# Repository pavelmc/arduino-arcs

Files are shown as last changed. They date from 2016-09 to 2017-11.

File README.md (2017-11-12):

# Arduino-Arcs #

_**Amateur Radio Control & Clocks (RF) Solution**_

This is an amateur approach to a radio control solution with clock (RF sources) generation (VFO and BFO) for homebrewed and old (not frequency synthesized) transceivers; of course based on the Arduino platform.

You can [take a peek here](http://www.qrz.com/db/wj6c) to see what's it looks like in the bench.

## Motivations ##

This project arose as a solution for the Cuban hams who have built a simple QRP transceivers but lacks the principal part: a digital controller to avoid the "DRIFT" and get some of the standard radio features a ham's needs today in a radio.

[Juan Carlos (WJ6C)](http://www.qrz.com/db/wj6c), Axel (CO6ATL), [Heriberto (CM2KMK)](http://www.qrz.com/db/wj6c) and many others hams were trying with some Arduino sketches found on the network until [I (CO7WT)](http://www.qrz.com/db/co7wt) decided to give a hand using my skills and expertise on MCU programming with [Jal for the PICs](http://www.justanotherlanguage.com) & [Arduino](http://www.arduino.cc).

This code is the result of a group of Cubans that joint together to fulfill the expectations for a simple, affordable and yet modern radio logic controller for homebrewed radios that any ham in the world can use.

This work is and always will be in constant development, this must be always considered a Beta version.

## Hardware ##

We are using the ubiquitous Arduino boards for the main brain, a list of the needed hardware follows.

- Arduino as the brain; developed for the Arduino Uno R3 as base, but it's adaptable to other boards, we are using mainly the Mini & Mini Pro now (Yes it's less than 16 kb at the end)
- LCD 16 columns and 2 lines as display (LiquidCrystal default Arduino lib)
- Si5351 as VFO and BFO, any of the breakout board out there will work, we choose to use a embedded code for the Si5351 control. Our code is a modified version of one of the examples in the [QRP Labs site](http://qrp-labs.com) (with my mods to allow two outputs instead of only one) and trick learned from [DK7IH](https://radiotransmitter.wordpress.com/category/si5351a/) to eliminate the unpleasant clicks when tunning. You can use it as a full library named [Si5351mcu here](http://github.com/pavelmc/si5351mcu).
- For the human interface part we use a bunch of [analog push buttons with dual functions](https://github.com/pavelmc/BMUx/) and a [rotary encoder](https://github.com/mathertel/RotaryEncoder) + [push button](https://github.com/thomasfredericks/Bounce2/).
- Since September of 2016 the sketch has CAT support, if you are using an Arduino R3 or others with a USB port you are done; if not you need any of the [cheap ebay USB to RS-232/TTL converters](http://www.google.com/q=cp-2021+USB+serial+ttl+converter) just watch out for the correct drivers if you use any Windows OS.

You can see the schematic diagram (designed for an Arduino Uno R3 in mind) in the file sketch_schema.png (I can provide Fritzing files on request, but only the schematic part is ok.)

## Features implemented by now ##

- **Usual features** of normal commercial transceivers.
    - Two VFO (A/B)
    - RIT with +/- 9.99 Khz
    - Variable VFO speed in steps of 10hz, 100hz (Default), 1khz, 10khz, 100khz, 1Mhz (just push of the encoder)
    - Split for contest/pileups
    - VFOs A & B are preserved in the EEPROM across power cycle. _(See Note 1 below)_
- **S-Meter in the LCD** _(Vref is 5.0V)_ _(See Note 2 below)_
- **Relative TX power in the LCD** _(using the same S-Meter tech, no power calcs, yet)_
- Initially mono-band in 40m, but **adaptable to any band**
- **Full user customization** of the IF and BFO modes (side bands) via configuration menus. (The VFO is assumed always above the RF and side bands are adjusted, se notes on Si5351 noise)
- **Hot tunning of the parameters** when in configuration mode for ease the adjust.
- **Basic CAT control** (like a Yaesu FT-857D) using my GPL 3.0 [ft857d library](https://github.com/pavelmc/ft857d) _(See Note 3 below)_
- The sketch is coded with **feature segmentation in mind**, you can rule out the CAT support if you don't need it, disable the ugly S-meter or rule out all other HID and just compile with CAT to get a slim CAT radio solution that fits in a tiny ATMega8 core _(I'm no kidding, it do fit in that chip!)_
- **Memories** Using the internal EEPROM and limited to 100 (0-99), because the channel number is displayed in two LCD chars. Also you will get what your Chip has to offer: bigger chips my exceed the 100 mem channels count and get toped, but other not and you will have less than 100 mem channels.
- ** Scan in memories ** if you enable the memories in the compilation you have also the possibility of enable the scanning features to loop trough the active memories and stay in each one by a defined amount of time.

_**Note 1:** The firmware save the VFO info in a 10 minutes interval. Also a touch on the "VFO A/B" button will force an update_

_I was once concerned with the EERPOM wear out, but not anymore: The auto-save every 10 minutes **with a heavy use** of the transceiver can lead to about 3 years of life for the internal EEPROM _under datasheet conditions_. But you can expect at least x2 of that amount as the real world data shows (that's at least 6 years with heavy use or more than 10 years with little use)_

_Since October 2016 we are now using the new EEPROM.h library (since Arduino IDE 1.6.9 and later); that lib do a trick to preserve the internal EEPROM life against the wear out, so the real life of the EEPROM must be more than 6 years minimum, that for a **heavy daily use**._

_**Note 2:** You have two options for the SMeter graphics, the default now is a 26 steps solid bars like "|||||||||||||||" and the alternative is the old "1-3-5-7-9----" with a resolution of only 13 steps. You can change it via a #define in the code, read it._

_**Note 3:** If you use a regular Arduino board and upload the code via serial port you do have a bootloader in place. In this case when you setup your CAT program (in your PC) you will have to set the "retries" parameter to 3 or more and the "timeout" parameter to 500 msec or more to get the CAT working. (you will have to play with it a bit to get it working)_

_This is because the CAT setup process in your PC/software will reset the Arduino board (and hence the "radio")_

_Then the bootloader will introduce a short delay before our firmware kicks in and the PC may complain about "radio not answering to commands". The fix is in the previous paragraph. If you have no bootloader and upload the code via ICP you must not see this problems._

## Features in the TODO list ##

This are the wish list so far, with no particular order.

- Multi-band support with a function to jump quickly from band to band.
- Band selector for BPF switching via a external I2C port expander like the boards with the PCF8574, or alternatively a PIC programed to the task.
- Real Power and SWR measurements.
- Support for various LCDs, for example the Nokia 5110, some of the TFTs and some OLEDs.

## Ino, then Arturo, now Amake ##

Old users of this sketch may notice that it's now full Arduino IDE compatible _(since January/2017 with the release of the Arduino IDE version 1.8.0)_ and you don't need to make any more changes to the name of the file.

I use Ubuntu Linux for daily work here, and I don't like the Arduino IDE as a IDE. I use the [Geany IDE](http://www.geany.org) to code in Jal, Python, Arduino etc. In the past two projects helped me to link my Geany IDE to the Arduino tool-chain: [ino](https://github.com/amperka/ino) and it's folk [Arturo](https://github.com/scottdarch/Arturo/) when Ino reached the end of development. Thanks to the developers of this two projects for the great tools.

Since the release of the Arduino IDE version 1.8.0 it's possible to use a new tool "arduino-builder" that make possible to compile and upload a sketch entirely from the command line, but that tool is a nightmare to configure for the job in the command line.

And that was the born of [Amake](https://github.com/pavelmc/amake/), this a bash script that introduce a layer to get the compilation and uploading of arduino sketches from the command line like a breeze, and it's full Arduino IDE compatible. It's my contribution to make the life simpler ;-)

## Si5351 known issues ##

The Si5351 chip is not the panacea of the frequency generator (but it's a close one), as almost all good things in life it has a dark side, know more about in [this](https://github.com/pavelmc/arduino-arcs/Si5351_issues.md) document.

73 Pavel CO7WT.

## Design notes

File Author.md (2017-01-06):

# Author #

I'm Pavel Milanes, the main developer of this sketch and can be reached at pavelmc@gmail.com I'm an active amateur radio operator under the call sign CO7WT, and I live in Camagüey, Cuba, the Caribbean island, exactly at the FL11aj locator. I'm active from time to time around 7.125 Khz on 40m from 2200z to 0200z on weekdays.

## Acknowledge to direct & indirect contributors ##

This work is based on the previous work of these people (without their work this project may not exist):

 * [NT7S](https://github.com/etherkit/Si5351Arduino) for his work on the Silabs Si5351 and the Arduino library.
 * Ben Buxton & [mathertel](https://github.com/mathertel/RotaryEncoder) for the arduino rotary encoder library
 * [Thomas Ouellet](https://github.com/thomasfredericks/Bounce2/) for the Bounce2 library
 * [SQ9NJE](http://sq9nje.pl) for the example codes and it's sketchs.
 * [AK2B](http://ak2b.blogspot.com) for his multifeatured VFO in which this code is based.
 * [WJ6C](www.frcuba.com) for the idea and support, this OM is the motor of this project.
 * [QRP Labs](http://qrp-labs.com) explanation and examples of libraries for the Si5351 with MCU (size) focus.
 * Many other hams elsewhere with critics, opinions, public code on the Internet and ideas.

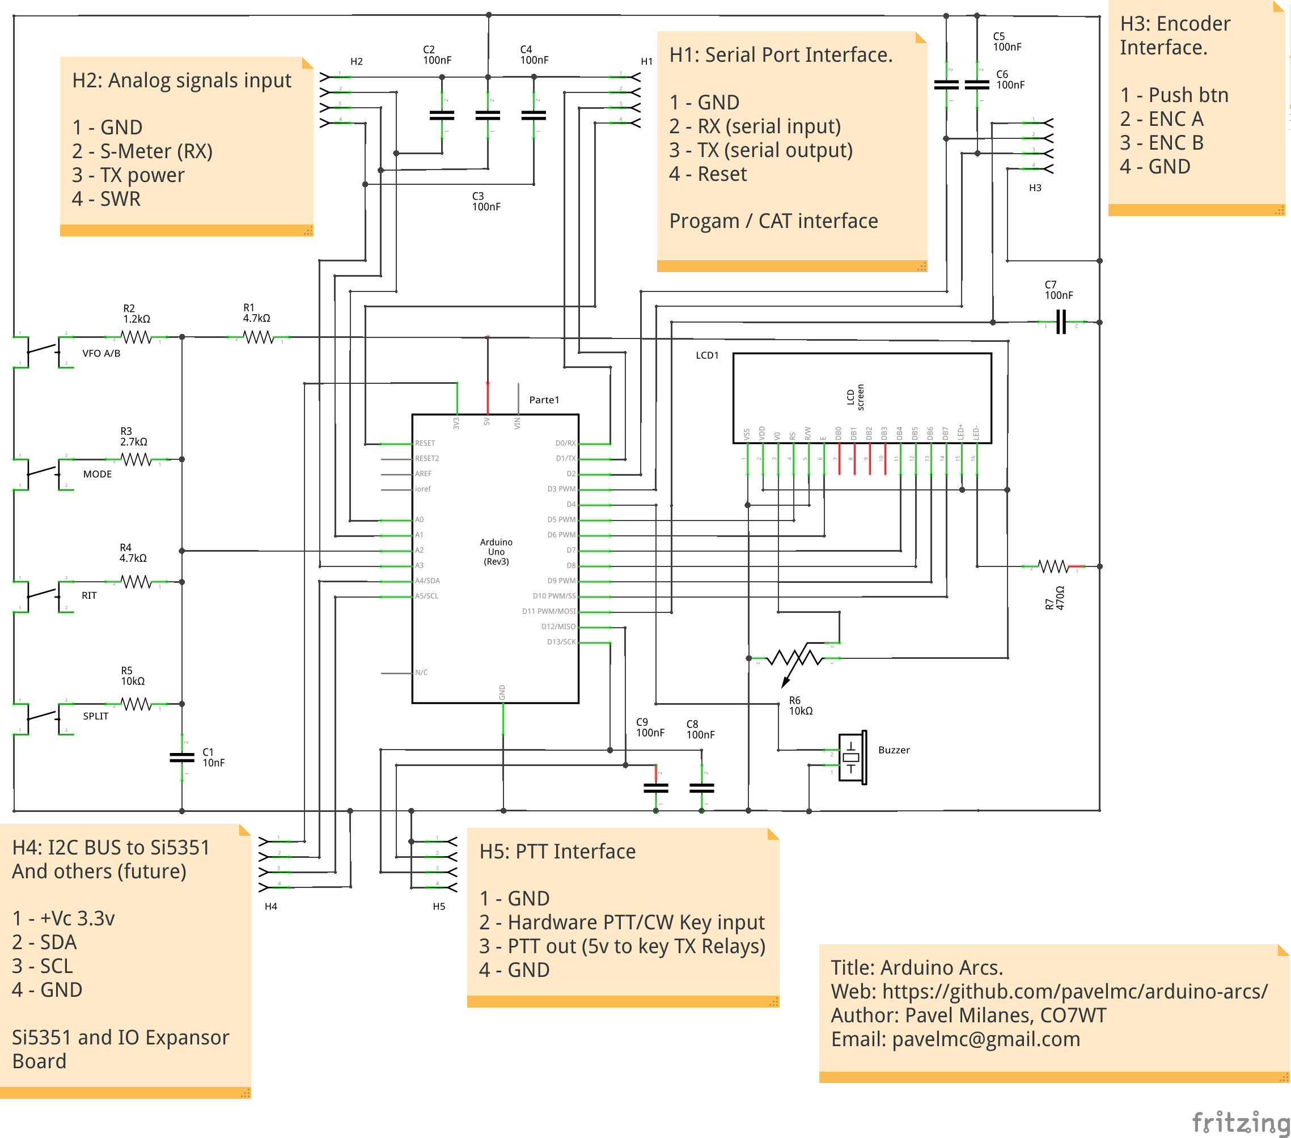
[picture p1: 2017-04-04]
sketch_schema.png

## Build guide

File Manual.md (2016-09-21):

Arduino ARCS Manual
=========================

# OUTDATED, will be upgraded soon #

This is a short manual to know how to operate the sketch and the button's functions. The sketch has two modes, the user's mode and the setup mode, let's review them

User mode
=========

General description
-------------------

The user mode is the natural way the hardware boots if you don't touch anything, yo will see the Arduino ARCS banner and a note of the firmware version, the memory firmware version and the author, then you will get the main screen.

The main screen is composed of two lines the top line and the bottom line, both lines has the same information for each of the two VFOs the sketch has, upper is VFO A and lower is VFO B. You know which VFO is selected by the ">" sign in front of it.

The frequency is printed grouped by units and separated by a dot to easy viewing, first the Mhz units, then the khz part and finally the Hz part.

The frequency is truncated at the 10th of hz part to be honest, the Si5351 has a resolution of 0.1 hz in our configuration and an accuracy of 0 ppm error against the reference crystal used (that's per the OEM datasheet), then all the accuracy is referenced to the accuracy of the reference crystal and it has (usually on free air) about 10 ppm of error; using a 27 Mhz xtal we can expect a extreme variation of about 270 hz with temperature, voltage and humidity fluctuations.

In the best case scenario if you have a relatively stable operating temperature and humidity you can get about less 10hz of variation normally under this conditions.

This is why we have not 1hz accuracy in place, we can implement it, sure, the chip will be happy moving in 1hz steps but that "accuracy" will be undermined by the real stability of the reference crystal unless you managed to get a temp oven for the crystal, and that is an overkill to out goal.

If you have a crystal in an oven and you want to use 1hz steps I will be happy to mod the sketch for you.

VFO button
----------

This Button toggles from the two available VFOs, as simple as that.

RIT button
----------

This button toggles the RIT function for the **active** VFO and will show the RIT detail in the other position, the RIT uses a +/- 9.9 Khz, so you can go further than that; this can be modified by software. When you have the RIT active and hit this button again, it will reset the VFO to the previous value as you expect.

The step on the RIT mode is fixed by software at 100hz, you can get it at the 10hz step if you change it on the source code in the sketch.

A note: when you have the RIT active on one VFO and you want to switch to the other VFO the active RIT will be reseted before the switch to the other VFO.

MODE button
-----------

The mode button change the mode of the **active** VFO in a closed loop from one of the predefined modes, so far: LSB > USB > CW and then back to LSB.

STEP button _(encoder push button)_
---------------------------------

The encoder push button has the control of the steps in the rotation of the encoder, pushing it will cycle steps in 10hz, 100hz, 1khz, 10khz, 100khz and 1 Mhz and then back to 10hz.

Upon the modification of the step, the LCD will show the value in the area used to show the S-meter bargraph for about three seconds.

Encoder
-------

The encoder is simply the vernier to selecting the frequency of the active VFO in the steps selected by the push button described before.

SETUP mode
==========

The setup mode is reached by powering on the circuit and holding the encoder button pressed until you see the acknowledge in the LCD for it being on the SETUP mode.

In the setup mode you will find a menu with the following options to select and change on the encoder rotation and push.

 * IF frequency
 * VFO A start frequency
 * VFO B start frequency
 * VFO frequency for the LSB mode
 * VFO frequency for the USB mode
 * VFO frequency for the CW mode
 * VFO A start mode
 * VFO B start mode
 * XFO frequency
 * Si5351 PPM error correction

All this options are cycled via the encoder rotation in one or another direction and selected via the encoder push button; we will describe the buttons use in the setup mode and be aware that they change a little in the setup mode, we will name it as the usual function and will name the special function between parenthesis.

Encoder push button _(Select & Confirm)_
-----------------------------------

This button is used to select the option in the main menu to be modified, and also to confirm it's change after it was modified and get it back to the main menu saving it on the EERPOM.

MODE button _(Cancel)_
--------------------

This button has effect only when you have selected and option in the main menu and it's purpose is to leave this option unchanged and get back to the main menu. If you changed the value of an option selected (by rotating the encoder) but you want to cancel it's modification this option is what you need.

RIT button _(Step)_
-----------------

This button has only effect when you have selected to modify a menu entry that leads to a numeric option (for example frequencies, PPM error, etc.) and it will change the step for the encoder rotation showing the value selected in the LCD until you rotate the encoder.

VFO button _(Reset)_
------------------

This button has a special meaning in the options refereed to LSB & USB BFO frequencies and the Si5351 PPM correction. Pressing this buttons will reset the values of that option to it's default values as this:

 * BFO LSB frequency = -15000
 * BFO USB frequency = +15000
 * BFO CW frequency = +10000
 * Si5351 PPM error correction = 0

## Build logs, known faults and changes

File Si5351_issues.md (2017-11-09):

# Si5351 Clock generator issues #

There are some founded worries about the use of the Si5351 Clock generator in transceiver business, and now with more and more builders using it, that problems are beginning to fade away.

This article will grow with experience notes about the problems and our experience about them. For the record, we have so far 5 different setups testing this sketch + hardware.

* BitX 20 _(converted to 40m, IF 8.2158 Mhz from a FT-747GX SSB filter, **CO7WT**)_
* Anritsu transceiver _(Unknown model, IF1 1.6 Mhz, IF2 455 Khz, **CO7LX**)_
* RFT SEG-15 _(WWII transceiver, IF1 28.2 Mhz, IF2 200 Khz, **CO7KD**)_
* Furuno FS1000 _(IF 9 Mhz, **CO7YB**)_
* Homebrew 500Khz singe conversion SSB radio _(Using a SSB filter from a USSR/CCCP "KARAT" transceiver, **CM7MTL**)_

Please note that almost all of this radios are actually kind of Frankenstein's cousins, as they preserve the main RF/IF chain from the mentioned radios, but can have another final stage (homebrewed or borrowed for a commercial unit) as well as chassis/front panels, etc.

## Crosstalk ##

Some users are pointing that the outputs of the chip is not clean enough for the use in heterodyne transceivers, [here you can see of what we are talking about](http://nt7s.com/2014/12/si5351a-investigations-part-8/), as you can see, some of the signal of one output can sneak into the other output, this is a proved bad thing.

Then the question now is: **how bad is it?**

The graphs in the last link shows the worst scenario, you can see that the worst case is only about -35 dB down the main frequency, that will result in about 25mW of the spurious frequency at the output of a main signal with 100W for the fundamental frequency.

With proper measures in design and other tricks (Bandstop/bandpass filters) you can get that crosstalk down below 50dB and the problem can be minimized at the point to be almost eliminated.

### Experience from our side ###

From a technician point of view with laboratory grade equipment, you are gonna find the crosstalk, it's there. From a normal homebrewer with COTS (Cost Off The Shelf) equipment it's not a big deal on reception and it has a no-noticeable impact on your transmission even with 150W in one of our local setups.

## Square wave output ##

Thanks to Mr. Fourier we know that square waves are a pure sine wave of the fundamental frequency plus all the harmonics of it until infinity... but a signal full of it's harmonics is a bad thing in a VFO or any other place where we need a pure sine signal, right?

That's why we designed the sketch to always use a final VFO frequency **above** the fundamental RF frequency and all the outputs of the chips will be followed with a matched low pass or a band pass filter to get rid of the most of the harmonics to minimize this problem.

Reception is affected in a different manner even when the VFO is over the RF; if you had to generate a BFO or a VFO signal below 2Mhz you will get more and more spurious spikes across the spectrum. Eventually at a BFO of 455/500 kHz you will need some filtering in place for a proper operation.

A trick from one of our builders CO7LX: he has a 1rst IF of 1.6 MHz then a second IF of 455 kHz. The reception with the BFO at 455 kHz coupled directly (just a dc blocking capacitor) was really poor. After inspection wit and SDR we noted a lot of spurious spikes and an unusual high noise floor.

As this signal is fixed and if needed just moved a couple of kHz we make a simple filter with two TOKO IF cans coupled back to back to form a crude and yet simple band pass filter and we managed to push down the noise floor and the numerous spurious signals to a very pleasant level.

### Experience from our side ###

The simple fix is to put a low pass filter for the used frequency range, or even better, a band pass filter you will be safe and this will do the job, believe us, this is a "must" not an "if".

## Jitter & phase noise ##

There are some sources talking about the jitter in the output frequencies, but this author can't find any technical info on the web about how bad is it.

For SSB communications we (humans) can tolerate a jitter of about 2-5 hz without noticing it, and free running LC oscillators can have more than that and we can deal with that, so I think this will not defeat the purpose of this Chip as a frequency generator in the cheap ham market.

The code for managing the Si5351 uses a integer division always, with that we get sure you get as low jitter and phase noise as possible.

## Birdies and Background Noise ##

In almost all setups out there in the internet you will find a few users talking about the birdies in the receiver and even about an artificial (high) background noise, well, after experimentation with this setup with a few receiver configurations here in Cuba I can tell you this:

1 - Not all birdies comes from the Si5351, some are Arduino and/or LCD related.

In one of my setups I tested to power off the Arduino and the LCD but leaving the Si5351 powered and generating the frequency for the rest of the receiver chain, I can spot at least two birdies that will go completely off once you erase the Arduino + LCD from the equation, so the Si5351 is not the sole culprit. Also the background noise levels drops.

2 - Yes, you can experiment an artificially (high) background noise, mainly from the Arduino talking with the LCD.

In one of the developing stages, early in the barGraph introduction I suddenly experienced a high background noise, after firing my Yaesu FT-747GX on and check I can confirm that the noise comes from inside the hombrewed radio...

Later investigations revealed that the MCU (Arduino) to LCD communications and the ADC reading generate a lot of noise, high enough to mask some times the weak signals and even get at annoying levels at certain frequencies.

To deal with that this sketch minimizes the writes to the LCD to the least possible and the results are very good compared to the initials with the all time refreshing LCD.

A user on a mailing list commented recently that keeping the Arduino + LCD + Si5351 module in a shielded compartment away from the sensitive RF components can eliminate this "artificially (high) background noise". Local testing made by Soris CO7YV proved that this is a great help to make the radio even quieter.

## Datasheet tells three outputs, but in practive it's a gamble of 2+? ##

The internals of the Si5351 are described in depth in the datasheet and further publications, long story short: the Chip has an external crystal as a reference for two (2) independent PLL VCOs in the VHF to UHF range, then you select a chain of divisors to process that VCOs outputs to get your desired frequency.

The trick is that with three outputs you will have to share two of the outputs with a common PLL VCO frequency and you will have one of them that can be expressed in the correct math to get right on the frequency under certain circumstances.

### Experience from our side ###

In the RFT SEG-15 we test the use of the three frequencies from the sketch, one for the VFO with and independent VCO (29 to 60 Mhz) and then a XFO of 28.0 Mhz and a BFO of 200 Khz sharing the same VCO.

Strange things happened when we start to tune the frequencies out in the radio: the BFO will not move in steps of less than 150 Hz even if you set a step of 1 Hz, further investigations revealed that the library was trading stability (aka: struggle to keep the output active) vs. accuracy of the output.

In this configuration we found that with a 28.0 Mhz and a another less than 1 Mhz output, sharing the same VCO inside the Si5351 we face accuracy problems on the < 1 Mhz output.

So we sacrificed the XFO and go back to use the original crystal XFO inside the radio, taking that into account in the sketch: for the RFT SEG-15 the XFO is taken into account and used on the calculations but not activated in any way.

That lead to the desision of using just two of the 3 outputs of the Chip, almost all radio manufacturers use a real crystal for the fixed conversion from the 1rst to the 2nd IF; please do use it.

## Resume ##

There are many hams that are building transceivers with this chip (Si5351) and posting the results on the web, none of them have reported any of this mentioned problems as an impairment for that particular radio. So far in our experiments, we are confirming this, the Si5351 is suited to the job.

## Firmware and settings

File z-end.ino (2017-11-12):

/******************************************************************************
 *
 * This file is part of the Arduino-Arcs project, see
 *      https://github.com/pavelmc/arduino-arcs
 *
 * Copyright (C) 2016...2017 Pavel Milanes (CO7WT) <pavelmc@gmail.com>
 *
 * This program is free software under the GNU GPL v3.0
 *
 * ***************************************************************************/


// main setup function
void setup() {
    // set the defult values, before restoring theEEPROM ones
    setDefaultVals();

    #ifdef CAT_CONTROL
        // CAT Library setup
        cat.addCATPtt(catGoPtt);
        cat.addCATAB(catGoToggleVFOs);
        cat.addCATFSet(catSetFreq);
        cat.addCATMSet(catSetMode);
        cat.addCATGetFreq(catGetFreq);
        cat.addCATGetMode(catGetMode);
        cat.addCATSMeter(catGetSMeter);
        cat.addCATTXStatus(catGetTXStatus);
        // now we activate the library
        cat.begin(38400, SERIAL_8N2);
    #endif

    #ifdef LCD
        #ifdef SMETER
            // LCD init, create the custom chars first
            // depending on the selected smeter type
            #ifdef SMETER_ALT
                lcd.createChar(0, bar);
                lcd.createChar(1, s1);
                lcd.createChar(2, s3);
                lcd.createChar(3, s5);
                lcd.createChar(4, s7);
                lcd.createChar(5, s9);
            #else
                // default
                lcd.createChar(0, full);
                lcd.createChar(1, half);
            #endif
        #endif  // smeter

        // now load the library
        lcd.begin(16, 2);
        lcd.clear();
    #endif  // nolcd

    #ifdef ABUT
        // analog buttons setup
        abm.init(KEYS_PIN, 3, 20);
        abm.add(bvfoab);
        abm.add(bmode);
        abm.add(brit);
        abm.add(bsplit);

        // how many memories this chip supports
        #ifdef MEMORIES
            memCount = (EEPROM.length() - MEMSTART) / sizeof(mmem);
            // self limiting the mem amount to 100 (0-99)
            // we have only two chars on the LCD and 100 mems are a lot
            if (memCount > 99) memCount = 99;
        #endif
    #endif

    #ifdef ROTARY
        // buttons debounce & PTT
        pinMode(btnPush, INPUT_PULLUP);
        dbBtnPush.attach(btnPush);
        dbBtnPush.interval(debounceInterval);
        // pin mode of the PTT
        pinMode(inPTT, INPUT_PULLUP);
        dbPTT.attach(inPTT);
        dbPTT.interval(debounceInterval);
        // default awake mode is RX
    #endif  // ROTARY

    // set PTT at the start to LOW aka RX
    pinMode(PTT, OUTPUT);
    digitalWrite(PTT, 0);

    // I2C init
    Wire.begin();

    // check the EEPROM to know if I need to initialize it
    if (checkInitEEPROM()) {
        // just if it's already ok
        loadEEPROMConfig();
    } else {
        #ifdef LCD
            // full init, LCD banner
            lcd.clear();
            lcd.setCursor(0, 0);
            lcd.print(F("Init EEPROM"));
            lcd.setCursor(0, 1);
            lcd.print(F("Please wait"));
        #endif  // nolcd

        // init eeprom.
        saveEEPROM();

        #ifdef MEMORIES
            wipeMEM();
        #endif

        // make a smart delay
        smartDelay();

        #ifdef LCD
            lcd.clear();
        #endif  // nolcd
    }

    #ifdef LCD
        // Welcome screen
        lcd.clear();
        lcd.print(F("  Aduino Arcs  "));
        lcd.setCursor(0, 1);
        lcd.print(F("Fv: "));
        lcd.print(FMW_VER);
        lcd.print(F("  Mfv: "));
        lcd.print(EEP_VER);
    #endif  // nolcd

    // A software controlling the CAT via USB will reset the sketch upon
    // connection, so we need turn the cat.check() when running the welcome
    // banners (use case: Fldigi)

    // make a smart delay
    smartDelay();

    #ifdef LCD
        lcd.setCursor(0, 0);
        lcd.print(F(" by Pavel CO7WT "));
    #endif  // nolcd

    // make a smart delay
    smartDelay();

    #ifdef LCD
        lcd.clear();
    #endif  // nolcd

    #ifdef ROTARY   // check for SETUP mode
        // if you have no analog buttons then
        // there is no meaning for the setup mode
        #ifdef ABUT
            // Check for setup mode
            if (digitalRead(btnPush) == LOW) {
                // sound signal
                beep();
                delay(50);
                beop();

                // rise the flag of setup mode for every body to see it.
                runMode = false;

                // beep signal to the user
                tone(4, 800, 250);
                delay(250);

                #ifdef CAT_CONTROL
                    // CAT is disabled in SETUP mode
                    cat.enabled = false;
                #endif

                #ifdef LCD
                    // we are in the setup mode
                    lcd.setCursor(0, 0);
                    lcd.print(F(" You are in the "));
                    lcd.setCursor(0, 1);
                    lcd.print(F("   SETUP MODE   "));
                    delay(2000);
                    lcd.clear();
                    // show setup mode
                    showConfig();
                #endif  // lcd
            }
        #endif // abut
    #endif  // rotary

    // setting up VFO A as principal.
    activeVFO = true;
    ptrVFO = &u.a;
    ptrMode = &u.aMode;

    // init the wire lib
    Wire.begin();

    // start the VFOa and it's mode
    updateAllFreq();

    // reset the Si5351 for the forst time
    Si5351_resets();
}


// forever loop
void loop() {
    #ifdef ROTARY
        // encoder check
        encoderState = encoder.process();
        if (encoderState == DIR_CW)  encoderMoved(+1);
        if (encoderState == DIR_CCW) encoderMoved(-1);
    #endif  // rotary

    // LCD update check in normal mode
    if (update and runMode) {
        #ifdef LCD
            // update and reset the flag
            updateLcd();
        #endif  // nolcd
        update = false;
    }

    #ifdef ROTARY
        // check Hardware PTT and make the RX/TX changes
        if (dbPTT.update()) {
            // state changed
            if (dbPTT.fell()) {
                // line asserted (PTT Closed) going to TX
                going2TX();

                // clear the memory scan flag if active
                #ifdef MEMORIES
                    #ifdef MEM_SCAN
                    mscan = false;
                    #endif
                #endif
            } else {
                // line left open, going to RX
                going2RX();
            }

            // update flag
            update = true;
        }

        // debouce for the push
        dbBtnPush.update();
        tbool = dbBtnPush.fell();

        if (runMode) {
            // we are in normal mode

            // step (push button)
            if (tbool) {
                // beep
                beep();

                // VFO step change
                changeStep();
                update = true;
            }

            #ifdef SMETER
                // Second line of the LCD, I must show the bargraph only if not rit nor steps
                if ((!ritActive and showStepCounter == 0) and smeterOk)
                    showBarGraph();
            #endif
        }


        #ifdef ABUT     // no setup mode if no analog buttons to change it
            if (!runMode) {
                // setup mode

                // Push button is step in Config mode
                if (tbool) {
                    // change the step and show it on the LCD
                    changeStep();
                    #ifdef LCD
                        showStep();
                    #endif     // nolcd
                }

            }
        #endif // abut
    #endif  // rotary

    // timed actions, it ticks every 1/4 second (250 msecs)
    if ((millis() - lastMilis) >= TICK_INTERVAL) {
        // Reset the last reading to keep track
        lastMilis = millis();

        #ifdef SMETER
            // I must sample the input for the bar graph
            smeter();
        #endif

        // time counter for VFO remember after power off
        if (qcounter < SAVE_INTERVAL) {
            qcounter += 1;
        } else {
            // the saveEEPROM has already a mechanism to change only the parts
            // that has changed, to protect the EEPROM of wear out
            saveEEPROM();
            qcounter = 0;
        }

        // step show time show the first time
        if (showStepCounter >= STEP_SHOW_TIME) {
            #ifdef LCD
                showStep();
            #endif  // nolcd
        }

        // decrement timer
        if (showStepCounter > 0) {
            showStepCounter -= 1;
            #ifdef SMETER
                // flag to redraw the bar graph only if zero
                if (showStepCounter == 0) barReDraw = true;
            #endif
        }
    }

    #ifdef CAT_CONTROL
        // CAT check
        cat.check();
    #endif

    #ifdef ABUT
        // analog buttons check
        abm.check();
    #endif

    #ifdef MEMORIES
        #ifdef MEM_SCAN
            // memory scan timming check
            checkMemScan();
        #endif
    #endif
}

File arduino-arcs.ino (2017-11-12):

/*******************************************************************************
 *
 *            ARCS - Amateur Radio Control & Clock Solution
 *           -----------------------------------------------
 * A full QRP/Hombrew transceiver control with RF generation, the Cuban way.
 *
 * Copyright (C) 2016...2017 Pavel Milanes (CO7WT) <pavelmc@gmail.com>
 *
 * This work is based on the previous work of these great people:
 *  * NT7S (http://nt7s.com)
 *  * SQ9NJE (http://sq9nje.pl)
 *  * AK2B (http://ak2b.blogspot.com)
 *  * QRL Labs team (http://qrp-labs.com)
 *  * WJ6C for the idea and hardware support.
 *  * Many other hams with code, ideas, critics and opinions
 *
 * Latest version is always found on the Github repository (URL below)
 * https://www.github.com/pavelmc/arduino-arcs/
 *
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
 * You should have received a copy of the GNU General Public License
 * along with this program.  If not, see <http://www.gnu.org/licenses/>.
*******************************************************************************/

/*******************************************************************************
 * Important information you need to know about this code & Si5351
 *
 * We use a embed Si5351a control code that presume this:
 *  * We use CLK0 & CLK1 ONLY
 *  * CLK0 use PLLA & CLK1 use PLLB
 *  * CLK0 is employed as VFO (to mix with the RF from/to the antenna)
 *  * CLK1 is employed as BFO (to mix with the IF to mod/demodulate the audio)
 *  * We use the full power in all outputs (8mA)
 *
 *  * Please have in mind that this IC has a SQUARE wave output and you MAY
 *    need to apply some kind of low-pass/band-pass filtering to smooth it
 *    and get rid of the nasty harmonics.
 *  * If you generate a BFO below 1Mhz you MUST filter the output of that CLK.
 *    The output of the Si5351 is harmonic rich below 1Mhz and you will NEED
 *    the filtering because those harmonics are close enough of the fundamental.
 ******************************************************************************/

/****************************** FEATURES SEGMENTATION *************************
* Here we activate/deactivate some of the sketch features, it's just a matter
* of comment out the feature and it will keep out of compilation (smaller code)
*
* For example: one user requested a "headless" mode: no lcd, no buttons, just
* cat control via serial/usb from the PC. for that we have the headless mode.
* Tip: uncomment th LCD define and you will have it.
*******************************************************************************/

// You like to have CAT control (PC control) of the sketch via Serial link?
#define CAT_CONTROL True

// Rotary and push control?
#define ROTARY True

// Analog button support?
// please note that if no rotary then abut is disabled
#define ABUT True

// Memories?
#define MEMORIES True   // hard limited to 99 mems (~80 on the ATMEga168)
                          // because we have only two spaces to represent that

// Also you want to scan over enabled memories?
#define MEM_SCAN True

// Smeter on the LCD?
#define SMETER True

// You have two alternatives for the SMeter graphics
// The default is a simple bar with 24 points (high) resolution
// The alternative is a low resolution one with 12 points
// but numbers in the 1-3-5-7-9-+20
//
// If you want the alternative just uncomment this code below
// the alternative willl cost you about 10 bytes of firmware
//#define SMETER_ALT True

// do you have an LCD?
#define LCD True

// if you want a headless control unit just comment the line above to
// effectively disable the LCD, when you have no LCD then there is no
// meaning for buttons, memories, rotary encoder, etc.
// You will get just CAT control

#ifndef LCD
    // no smeter
    #ifdef SMETER
        #undef SMETER
    #endif

    // no Analog Buttons
    #ifdef ABUT
        #undef ABUT
    #endif // abut

    // no rotary ot push buttons
    #ifdef ROTARY
        #undef ROTARY
    #endif // rotary

    // no memories
    #ifdef MEMORIES
        #undef MEMORIES
    #endif // memories

    // YES CAT_CONTROL
    #ifndef CAT_CONTROL
        #define CAT_CONTROL True
    #endif  // cat control
#endif  // headless

// safety check for no rotary, if no rotary then abut has no use.
#ifndef ROTARY
    // no need for Analog Buttons
    #ifdef ABUT
        #undef ABUT
    #endif // abut

    // no memories, beacause no abut
    #ifdef MEMORIES
        #undef MEMORIES
    #endif // memories
#endif // rotary

// safety check for memories only when analog buttons are in use
#ifndef ABUT
    #ifdef MEMORIES
        #undef MEMORIES
    #endif // memories
#endif // abut

// default (non optional) libraries loading
#include <EEPROM.h>         // Internal EEPROM
#include <Wire.h>           // I2C

// The eeprom & sketch version; if the eeprom version is lower than the one on
// the sketch we force an update (init) to make a consistent work on upgrades
const byte EEP_VER = 8;
const byte FMW_VER = 16;

// structured data: Main Configuration Parameters
struct userData {
    byte fmwver = FMW_VER;
    byte eepver = EEP_VER;
    long ifreq;     // first or unique IF
    long if2;       // second IF, usually higher than the ifreq
    long a;         // VFO a
    byte aMode;     // VFO a mode
    long b;         // VFO b
    byte bMode;     // VFO b mode
    int usb;
    int cw;
    int ppm;
};

// declaring the main configuration variable for mem storage
// BEWARE: you can't use it outside a procedure or function
// the compiler is not happy with that.
struct userData u;

// The start byte in the eeprom where we put mem[0]
#define MEMSTART sizeof(u)

// the limits of the VFOs: full HF; you can tweak it with the
// limits of your particular hardware, again this are LCD diplay frequencies.
#define F_MIN       500000     // 500 kHz
#define F_MAX     30000000     // 30.0 MHz

// PTT IN/OUT pin
#define PTT     13              // PTT actuator, this will put the radio on TX
                                // this match the led on pin 13 with the PTT
#define inPTT   12              // PTT/CW KEY Line with pullup

#ifdef ROTARY
    // Enable weak pullups in the rotary lib before inclusion
    #define ENABLE_PULLUPS

    // If you have a half step encoder (you need two clicks to make a step)
    // uncomment this to get it working
    //#define HALF_STEP

    // include the libs
    #include <Rotary.h>         // https://github.com/mathertel/RotaryEncoder/
    #include <Bounce2.h>        // https://github.com/thomasfredericks/Bounce2/

    // define encoder pins
    #define ENC_A    3              // Encoder pin A
    #define ENC_B    2              // Encoder pin B
    #define btnPush 11              // Encoder Button

    // rotary encoder library setup
    Rotary encoder = Rotary(ENC_A, ENC_B);

    // the debounce instances
    #define debounceInterval  10    // in milliseconds
    Bounce dbBtnPush = Bounce();
    Bounce dbPTT = Bounce();
#endif  // rotary
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

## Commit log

2016-06-12 Change the default step on RIT to 100hz
2016-06-12 Fix about the step display and the use of 1hz steps only on USB/LSB/PPM items on the SETUP mode
2016-06-17 Feature: lower the Si5351 acuracy from 0.01 hz to 0.1hz to allow to climb as high as 160 Mhz, also make some notes about it
2016-06-18 Feature: a big step towards the user of analog buttons, that has to be polished a lot more, plus a few 1/10hz corections
2016-06-18 More changes related to the analog buttons
2016-06-18 Fix a bug abou the setup and pull up in the push button to close to the read for setup, this allows that 50% of the time it boots in setup mode, now it's fixed
2016-06-18 Change: we are now using the CLK2 for BFO. This is because I' m using a prebuilt board and it has it in that way to easy prototyping
2016-06-18 README changes: inclusion of Axel and Heriberto as former developers, step changes and note the use of an analog button lib
2016-06-19 Erased the schematics.jpg in favour of Fritzing diagrams
2016-06-19 Add Fritzing file and diagrams
    [sketch.fzz]
2016-07-24 Need to rework, but workable now for my hardware. BFO will be referenced to LSB and the USB one will be +BW of the filter as well as the CW one
2016-07-31 Big changes: camelcase variables, typos, and a lot of logic glue
2016-07-31 BUG: The VFO_A was init as 0.0; that's mine, a cut&paste problem
2016-08-11 Change the encoder processing to a procedure outsude of the main loop
2016-08-12 Fix: the continous updating bargraph makes a noticeable QRM to the receiver, for that we include a timer and update the bargraph with an moving average of the readings; this prove to be smooth & quie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
2016-08-18 Remove the MsTimer2 Library in favour of a millis comparing, the MsTimer2 was interfering with the IRQ routine and hang up the MCU
2016-08-18 Re-arrange the init for the wire lib, it has troubles with one of the shield, and re-arange also the use for two shield (they are identical)
2016-08-20 Remove some debug code and rise the capacitance load of the crystal to get a better start
2016-08-28 Features & Bug Fixes: We are now sensing the PTT in the D13 pin; The bargraph now has numbers on it (a rough guess); now the sketch use the serial to make a debug of what's going on inside at compile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
2016-08-28 Update to the fritzing files and separated senting for the bar in RX/TX modes, now A0 is for RX and A1 for RX, BEWARE this is against the 1.1v internal reference.
    [sketch.fzz]
2016-08-30 Some defaults adjusted, and the discovery of the unaccuracy of the Si5351 with the XFO & BFO for the RTF-SEG15 use case, see inside to get details
2016-09-07 Feature change: the buttons functions in SETUP are re-arranged per user request for a more logic one, change of one string of if for a switch
2016-09-08 Feature: we moved the PTT to 2 pins; we sense it from the outside world from one ping and generate it mean other pin. This is in preparation for the CAT library that needs to generate the PTT from in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
2016-09-16 rearrange of the encoder functions for a more logic navigation in the code
2016-09-16 Some optimizations: remove some defines and change the code to follow the logic of true is the default, false otherwise; some new functions to print string of chars and signs on the LCD; improve the 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
2016-09-18 Change the encoder way from interrupt to polling
2016-09-22 Fix: Fldigi & CAT, fldigi failed to bring the CAT up with a USB Arduino due to reset
2016-09-22 Feature: VFO status preserved on reboot, just change the VFO so save it before power off
2016-09-22 Doc Update: new feature
    [sketch.fzz]
2016-09-22 Schematic update and changed reference in the docs
    [sketch.fzz]
2016-09-22 Change: switch to AnalogButtons lib & code tidy up
2016-10-06 Final spin for the new analog buttons handling
2016-10-07 Bug fix: correct redrawn of the bargraph in the same space; plus tight button response
2016-11-07 Bug Fix: remove a debug Serial.print left behind that injects disrt in the CAT comms
2016-11-07 Feature selection: E/D Analog Buttons
2017-01-06 First step of the migration to a full Arduino environment
2017-01-06 Doc change to reflect full Arduino IDE 1.8.0 compatibility
2017-01-31 Remove non COLAB boards
2017-01-31 Update the schematic
2017-03-26 Beep feedback on buttons
2017-03-26 Fix freq response to CAT
    [fc_cat.ino]
2017-03-26 S-Meter fixing, and beep for the Step change
    [arduino-arcs.ino, ff-abuttons.ino, z-end.ino]
2017-03-26 Minor tweaks in the eeprom area, fix some bugs on the mem to display and +1 to the firmware/eeprom version
    [arduino-arcs.ino, fb-rotary.ino, fe-eeprom.ino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]
2017-03-26 Fix for the ppm correction procedure in the SETUP mode
    [arduino-arcs.ino, fa-lcd.ino, fd-si5351.ino]
2017-03-27 Channel number show now in HEX format, allows to display up to 256 channels in just two digits; also defaults to 100 Hz steps in VFO mode
2017-04-04 Schematic update
2017-04-04 Schematic Resistor value update
2017-04-04 Fix: Si5351 ppm not loaded back & applied from EEPROM on power cycle.
    [fe-eeprom.ino]
2017-11-09 Regression, load the I2C lib, that was an mistake
    [z-end.ino]
2017-11-10 Semantic change for the LCD and headlees mode, and other #define logic glue
2017-11-10 More combinations for the analog buttons resistors
2017-11-12 Several Bugs fixed on SETUP mode and some code optimizations for small size
    [arduino-arcs.ino, fa-lcd.ino, z-end.ino]
2017-11-12 Fix to some #defines about the SMETER and add the Memory Scan feature
    [arduino-arcs.ino, fe-eeprom.ino, ff-abuttons.ino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]
2017-11-12 Move ssb filter from 2.4 to 3.2kHz

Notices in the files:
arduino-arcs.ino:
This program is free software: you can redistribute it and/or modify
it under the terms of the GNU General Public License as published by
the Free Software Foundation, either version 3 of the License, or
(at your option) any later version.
